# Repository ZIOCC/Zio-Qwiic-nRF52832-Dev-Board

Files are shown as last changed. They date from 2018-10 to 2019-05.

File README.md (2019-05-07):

# Zio Qwiic nRF52832 Dev Board

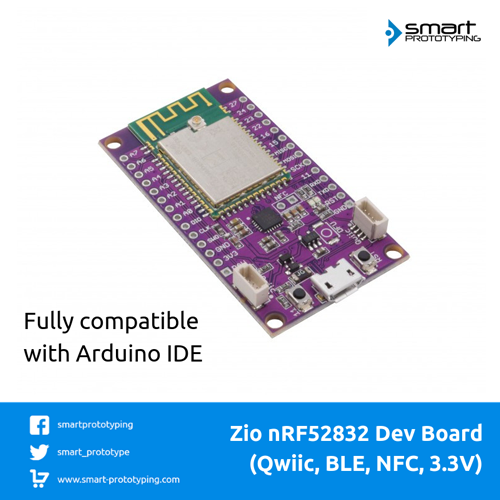
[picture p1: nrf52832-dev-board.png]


> This product can be available for purchase [here](https://www.smart-prototyping.com/Zio-nRF52832-Dev-Board-Qwiic-NRF-BLE).

> If you're looking for the nRF52832 Bluetooth module, you can check it out [here](https://www.smart-prototyping.com/nrf52832-Bluetooth-NFC-Module)

#### Description

This nRF52832 Dev Board is based on a well designed nRF52832 BLE module (E73). We’ve flashed Adafruit’s nrf52 Arduino bootloader for you, which makes it compatible with Arduino IDE. The dev board is open source hardware, for any makers and engineers they can embed the nRF52832 module into their project once the prototype is verified. 

The board breakouts all the pins from the module, and the pins for the NRF antenna. There is one NFC antenna with the package, which can be easily soldered to the through holes. 

We also added two Qwiic connectors, so you can use our Qwiic modules to instantly start I2C projects.

For the main IC nRF52832, you can check it from Nordic official website [here](https://www.nordicsemi.com/Products/Low-power-short-range-wireless/nRF52832). 

> Note: the Pins are not pre-soldered.

#### Specification

* BLE MCU: nrf52832
* USB UART MCU: SILICON LABS CP2104
* Weight: 8.1g
* Dimension: 30.0 x 55.3mm

#### Links

* [nrf52832 Datasheet](http://infocenter.nordicsemi.com/pdf/nRF52832_PS_v1.4.pdf)
* [nrf52832 official link](https://www.nordicsemi.com/eng/Products/Bluetooth-low-energy/nRF52832)
* [nrf52832 module Schematic](https://www.smart-prototyping.com/image/data/2_components/Bluetooth/101920%20nrf52832%20Bluetooth%20Module%20(CE,%20FCC,%20Half-Cut%20Hole)/nrf52832_module_schematic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)
* [Eagle file and source file for Dev board](https://github.com/ZIOCC/Zio-Qwiic-nRF52832-Dev-Board)
* [Schematic for Dev Board](https://github.com/ZIOCC/Zio-Qwiic-nRF52832-Dev-Board/blob/master/Zio%20Qwiic%20nRF52832%20Dev%20Board%20Schematic%20PDF.pdf)
* [Adafruit nRF52 Arduino Bootloader](https://github.com/adafruit/Adafruit_nRF52_Arduino_Bootloader)

> ###### About Zio
> Zio is a new line of open sourced, compact, and grid layout boards, fully integrated for Arduino and Qwiic ecosystem. Designed ideally for wearables, robotics, small-space limitations or other on the go projects. Check out other awesome Zio products [here](https://www.smart-prototyping.com/Zio).

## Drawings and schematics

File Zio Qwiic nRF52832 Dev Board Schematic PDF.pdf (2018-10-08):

+3V3 | 4.7K ±1% | 4.7K ±1%

# F1 R¹

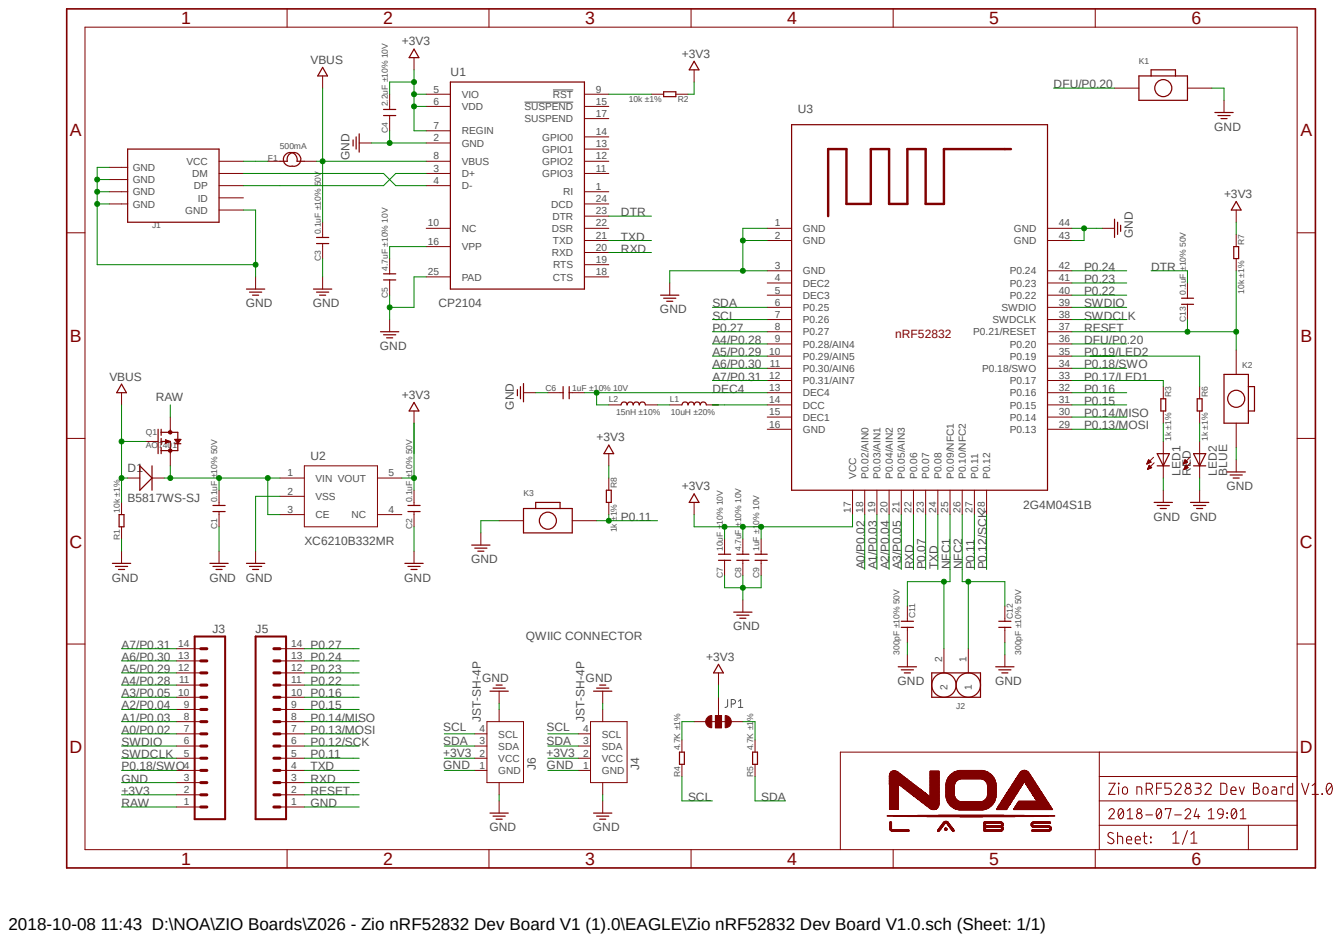
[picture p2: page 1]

2018-10-08 11:43 D:\NOA\ZIO Boards\Z026 - Zio nRF52832 Dev Board V1 (1).0\EAGLE\Zio nRF52832 Dev Board V1.0.sch (Sheet: 1/1)

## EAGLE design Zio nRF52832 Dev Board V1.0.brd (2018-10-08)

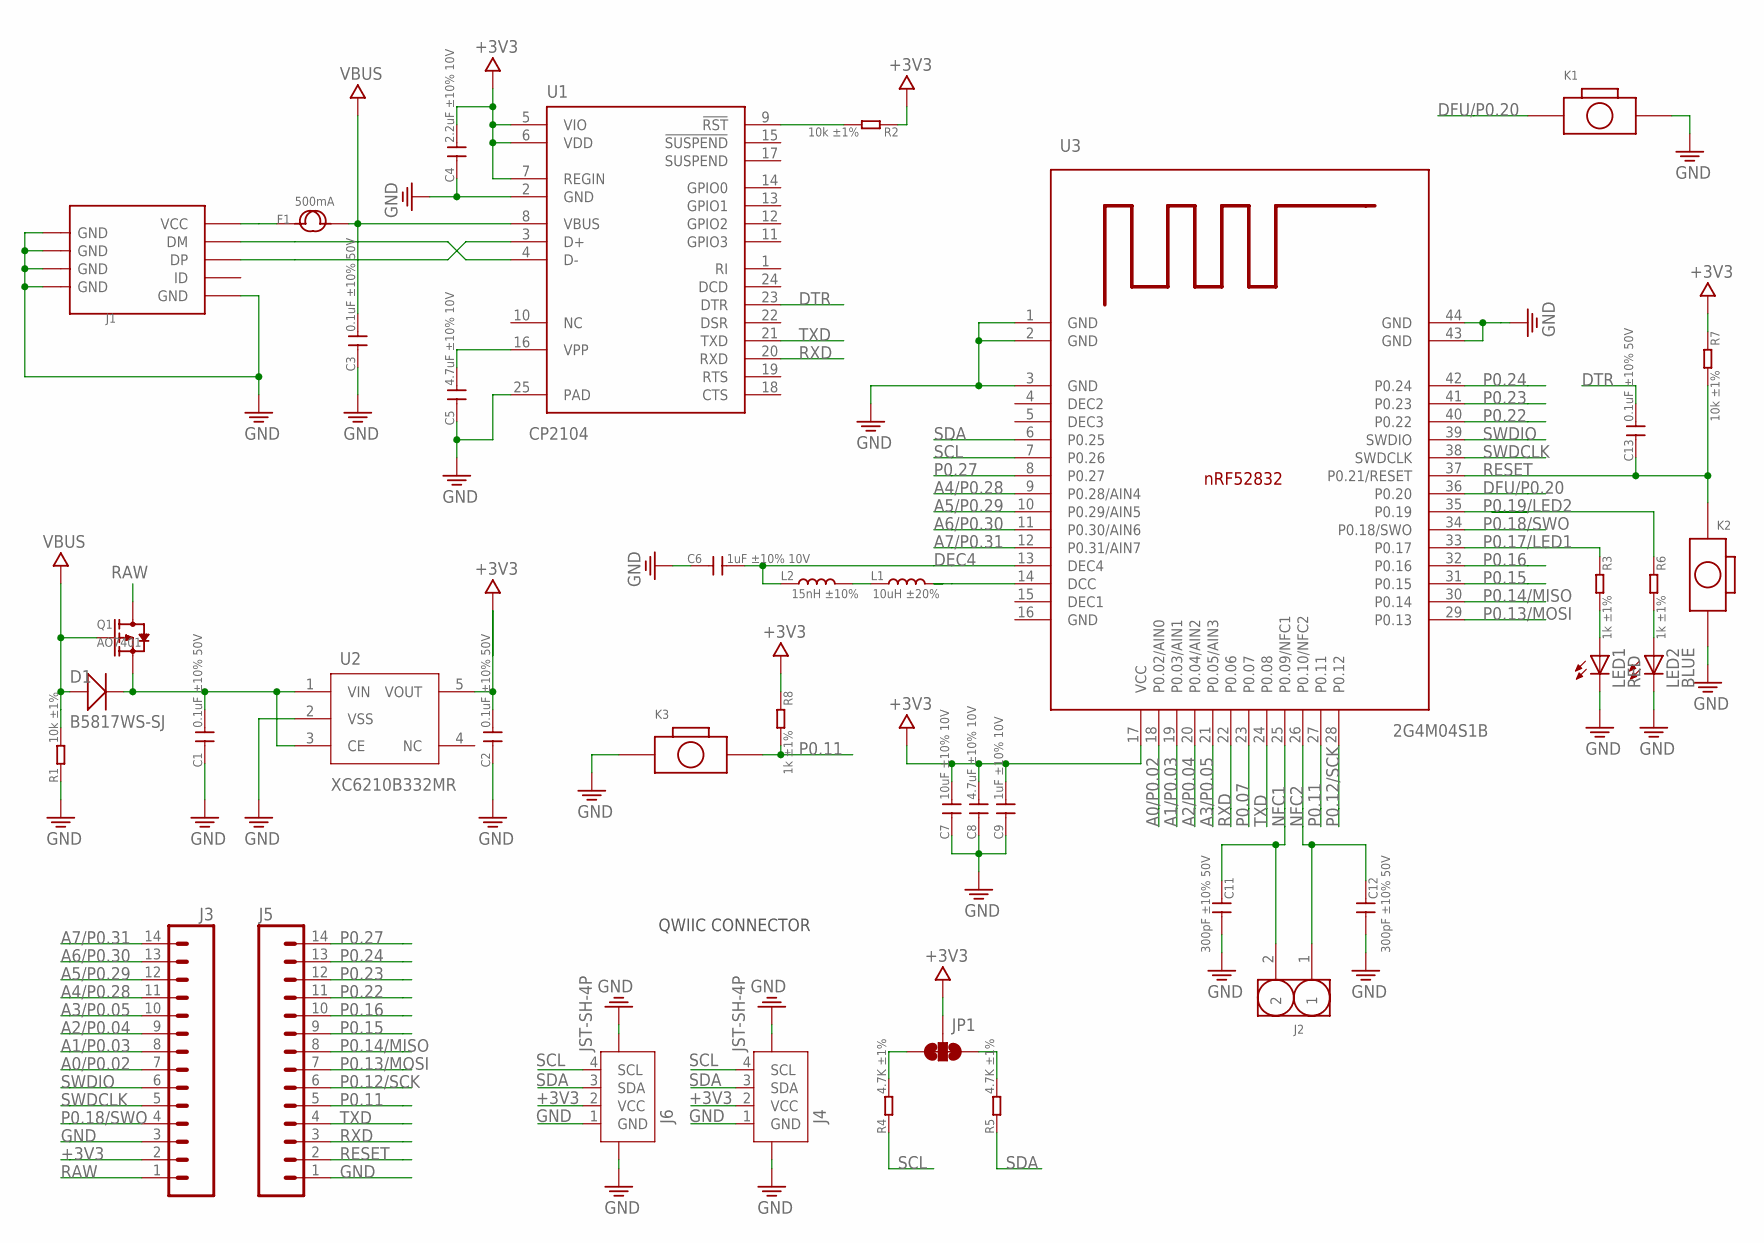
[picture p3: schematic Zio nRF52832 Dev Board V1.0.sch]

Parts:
C1, C2, C3, C13: 0.1uF ±10% 50V; C0603
C4: 2.2uF ±10% 10V; C0603
C5, C8: 4.7uF ±10% 10V; C0603
C6, C9: 1uF ±10% 10V; C0603
C7: 10uF ±10% 10V; C0603
C11, C12: 300pF ±10% 50V; C0603
D1: B5817WS-SJ; SOD323
F1: 500mA; 1206
J1: USB-MICROE; MICRO-SMD
J2: HEADER-2P-65/35MIL; 2P-2.54-65/35MIL
J3, J5: HEADER-14P; 14P-SCREW-2.54
J4, J6: JST-SH-4P; JST-SH-4P-90
JP1: SMT-JUMPER_3_2-NC_TRACE
K1, K2, K3: BOTTON-2PSKRKAEE020; SKRKAEE020
L1: 10uH ±20%; L0603
L2: 15nH ±10%; L0402
LED1: RED; CHIPLED_0603
LED2: BLUE; CHIPLED_0603
Q1: AO7401; SOT-323
R1, R2, R7: 10k ±1%; R0603
R3, R6, R8: 1k ±1%; R0603
R4, R5: 4.7K ±1%; R0603
U1: CP2104; QFN24_4X4
U2: XC6210B332MR; SOT23-5
U3: 2G4M04S1B; 2G4M04S1B_NRF52832

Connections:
+3V3: C2.2, C4.2, C7.2, C8.2, C9.2, J3.2, J4.2 (VCC), J6.2 (VCC), JP1.2, R2.1, R7.1, R8.1, U1.5 (VIO), U1.6 (VDD), U1.7 (REGIN), U2.5 (VOUT), U3.17 (VCC)
A0/P0.02: J3.7, U3.18 (P0.02/AIN0)
A1/P0.03: J3.8, U3.19 (P0.03/AIN1)
A2/P0.04: J3.9, U3.20 (P0.04/AIN2)
A3/P0.05: J3.10, U3.21 (P0.05/AIN3)
A4/P0.28: J3.11, U3.9 (P0.28/AIN4)
A5/P0.29: J3.12, U3.10 (P0.29/AIN5)
A6/P0.30: J3.13, U3.11 (P0.30/AIN6)
A7/P0.31: J3.14, U3.12 (P0.31/AIN7)
DEC4: C6.2, L2.1, U3.13 (DEC4)
DFU/P0.20: K1.1, U3.36 (P0.20)
DTR: C13.2, U1.23 (DTR)
GND: C1.1, C2.1, C3.1, C4.1, C5.1, C6.1, C7.1, C8.1, C9.1, C11.2, C12.2, J1.P5 (GND), J1.S1 (GND), J1.S2 (GND), J1.S3 (GND), J1.S4 (GND), J3.3, J4.1 (GND), J4.5, J4.6, J5.1, J6.1 (GND), J6.5, J6.6, K1.2, K2.2, K3.1, LED1.C, LED2.C, R1.1, U1.2 (GND), U1.25 (PAD), U2.2 (VSS), U3.1 (GND), U3.2 (GND), U3.3 (GND), U3.43 (GND), U3.44 (GND)
unnamed: L1.1, L2.2
unnamed: J1.P3 (DP), U1.3 (D+)
unnamed: R2.2, U1.9 (!RST!)
unnamed: J1.P2 (DM), U1.4 (D-)
unnamed: F1.1, J1.P1 (VCC)
unnamed: LED2.A, R6.2
unnamed: C5.2, U1.16 (VPP)
unnamed: LED1.A, R3.2
unnamed: L1.2, U3.14 (DCC)
unnamed: JP1.3, R4.2
unnamed: JP1.1, R5.2
NFC1: C11.1, J2.2, U3.25 (P0.09/NFC1)
NFC2: C12.1, J2.1, U3.26 (P0.10/NFC2)
P0.07: U3.23 (P0.07)
P0.11: J5.5, K3.2, R8.2, U3.27 (P0.11)
P0.12/SCK: J5.6, U3.28 (P0.12)
P0.13/MOSI: J5.7, U3.29 (P0.13)
P0.14/MISO: J5.8, U3.30 (P0.14)
P0.15: J5.9, U3.31 (P0.15)
P0.16: J5.10, U3.32 (P0.16)
P0.17/LED1: R3.1, U3.33 (P0.17)
P0.18/SWO: J3.4, U3.34 (P0.18/SWO)
P0.19/LED2: R6.1, U3.35 (P0.19)
P0.22: J5.11, U3.40 (P0.22)
P0.23: J5.12, U3.41 (P0.23)
P0.24: J5.13, U3.42 (P0.24)
P0.27: J5.14, U3.8 (P0.27)
RAW: J3.1, Q1.3 (D)
RESET: C13.1, J5.2, K2.1, R7.2, U3.37 (P0.21/RESET)
RXD: J5.3, U1.20 (RXD), U3.22 (P0.06)
SCL: J4.4 (SCL), J6.4 (SCL), R4.1, U3.7 (P0.26)
SDA: J4.3 (SDA), J6.3 (SDA), R5.1, U3.6 (P0.25)
SWDCLK: J3.5, U3.38 (SWDCLK)
SWDIO: J3.6, U3.39 (SWDIO)
TXD: J5.4, U1.21 (TXD), U3.24 (P0.08)
VBUS: C3.2, D1.+, F1.2, Q1.1 (G), R1.2, U1.8 (VBUS)
VIN: C1.2, D1.-, Q1.2 (S), U2.1 (VIN), U2.3 (CE)

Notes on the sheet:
QWIIC CONNECTOR

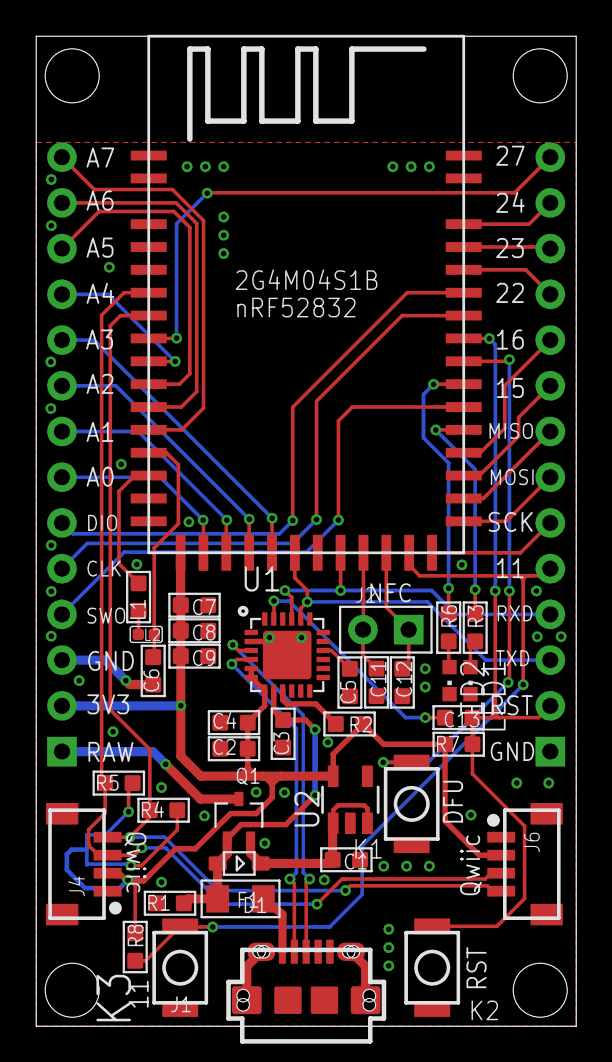
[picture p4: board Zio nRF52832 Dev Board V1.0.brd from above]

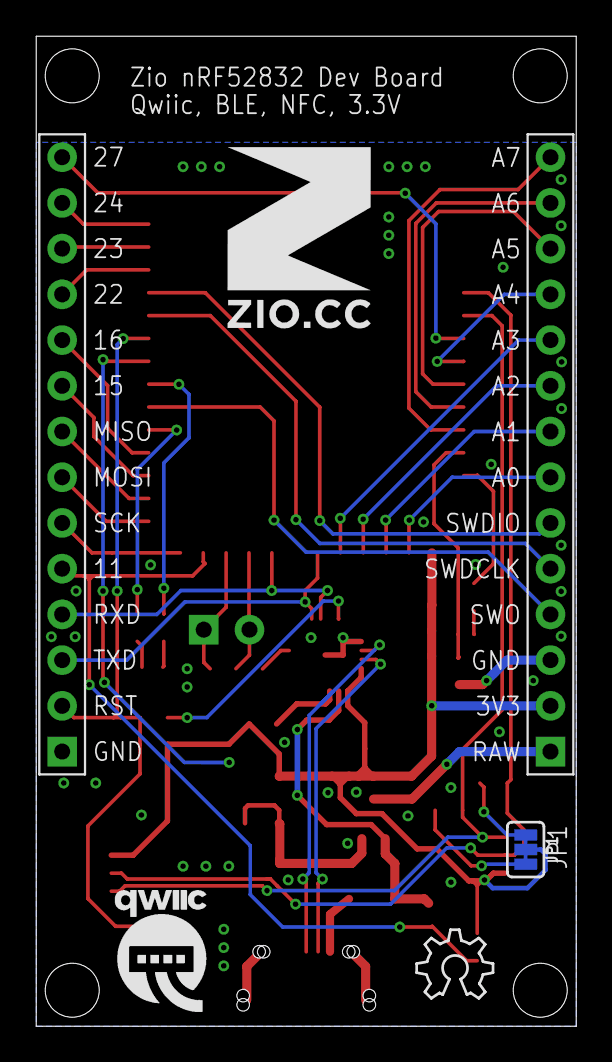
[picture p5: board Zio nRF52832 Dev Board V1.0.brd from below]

Board: 2 copper layers, 30.0 x 55.0 mm, 43 parts (6 on the bottom side), 49 nets.

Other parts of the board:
U$8: 10MM
U$11: QWIIC-LOGO-MEDIUM
U$12: OSHW_6X150_NOTEXT
